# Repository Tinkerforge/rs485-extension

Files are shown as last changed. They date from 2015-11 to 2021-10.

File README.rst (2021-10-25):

RS485 Extension
===============

This repository contains the hardware design files.
The software is included in the Master Brick software
and can be found at https://github.com/Tinkerforge/master-brick

Repository Content
------------------

hardware/:
 * Contains KiCad project files and additionally schematics as PDF

datasheets/:
 * Contains datasheets for sensors and complex ICs that are used

Hardware
--------

The hardware is designed with the open source EDA Suite KiCad
(http://www.kicad.org). Before you are able to open the files,
you have to install the Tinkerforge kicad-libraries
(https://github.com/Tinkerforge/kicad-libraries). You can either clone
them directly in hardware/ or clone them in a separate folder and
symlink them into hardware/
(ln -s kicad_path/kicad-libraries project_path/hardware). After that you
can open the .pro file in hardware/ with KiCad and from there view and
modify the schematics and the PCB layout.

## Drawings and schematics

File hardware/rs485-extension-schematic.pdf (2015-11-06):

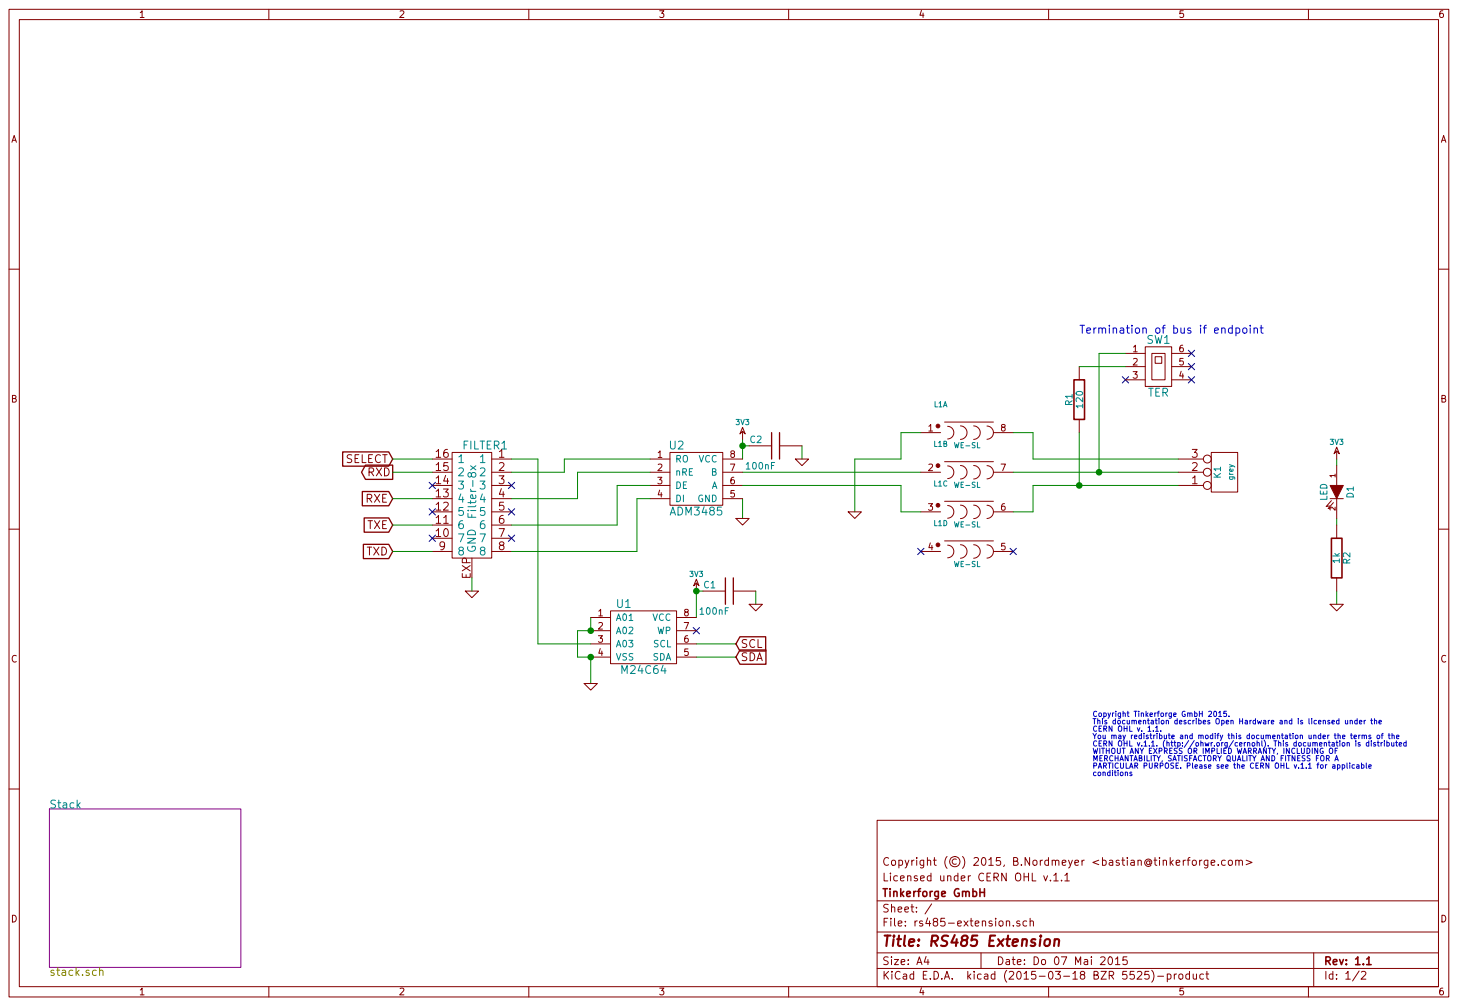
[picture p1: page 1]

Termination of bus if endpoint 1
6 SW1 TER R1 120

Copyright Tinkerforge GmbH 2015. This documentation describes Open Hardware and is licensed under the CERN OHL v. 1.1. You may redistribute and modify this documentation under the terms of the CERN OHL v.1.1. (http://ohwr.org/cernohl). This documentation is distributed WITHOUT ANY EXPRESS OR IMPLIED WARRANTY, INCLUDING OF MERCHANTABILITY, SATISFACTORY QUALITY AND FITNESS FOR A

PARTICULAR PURPOSE. Please see the CERN OHL v.1.1 for applicable
conditions

Licensed under CERN OHL v.1.1 Copyright (©) 2015, B.Nordmeyer <bastian@tinkerforge.com>

File: rs485-extension.sch Sheet: / Tinkerforge GmbH

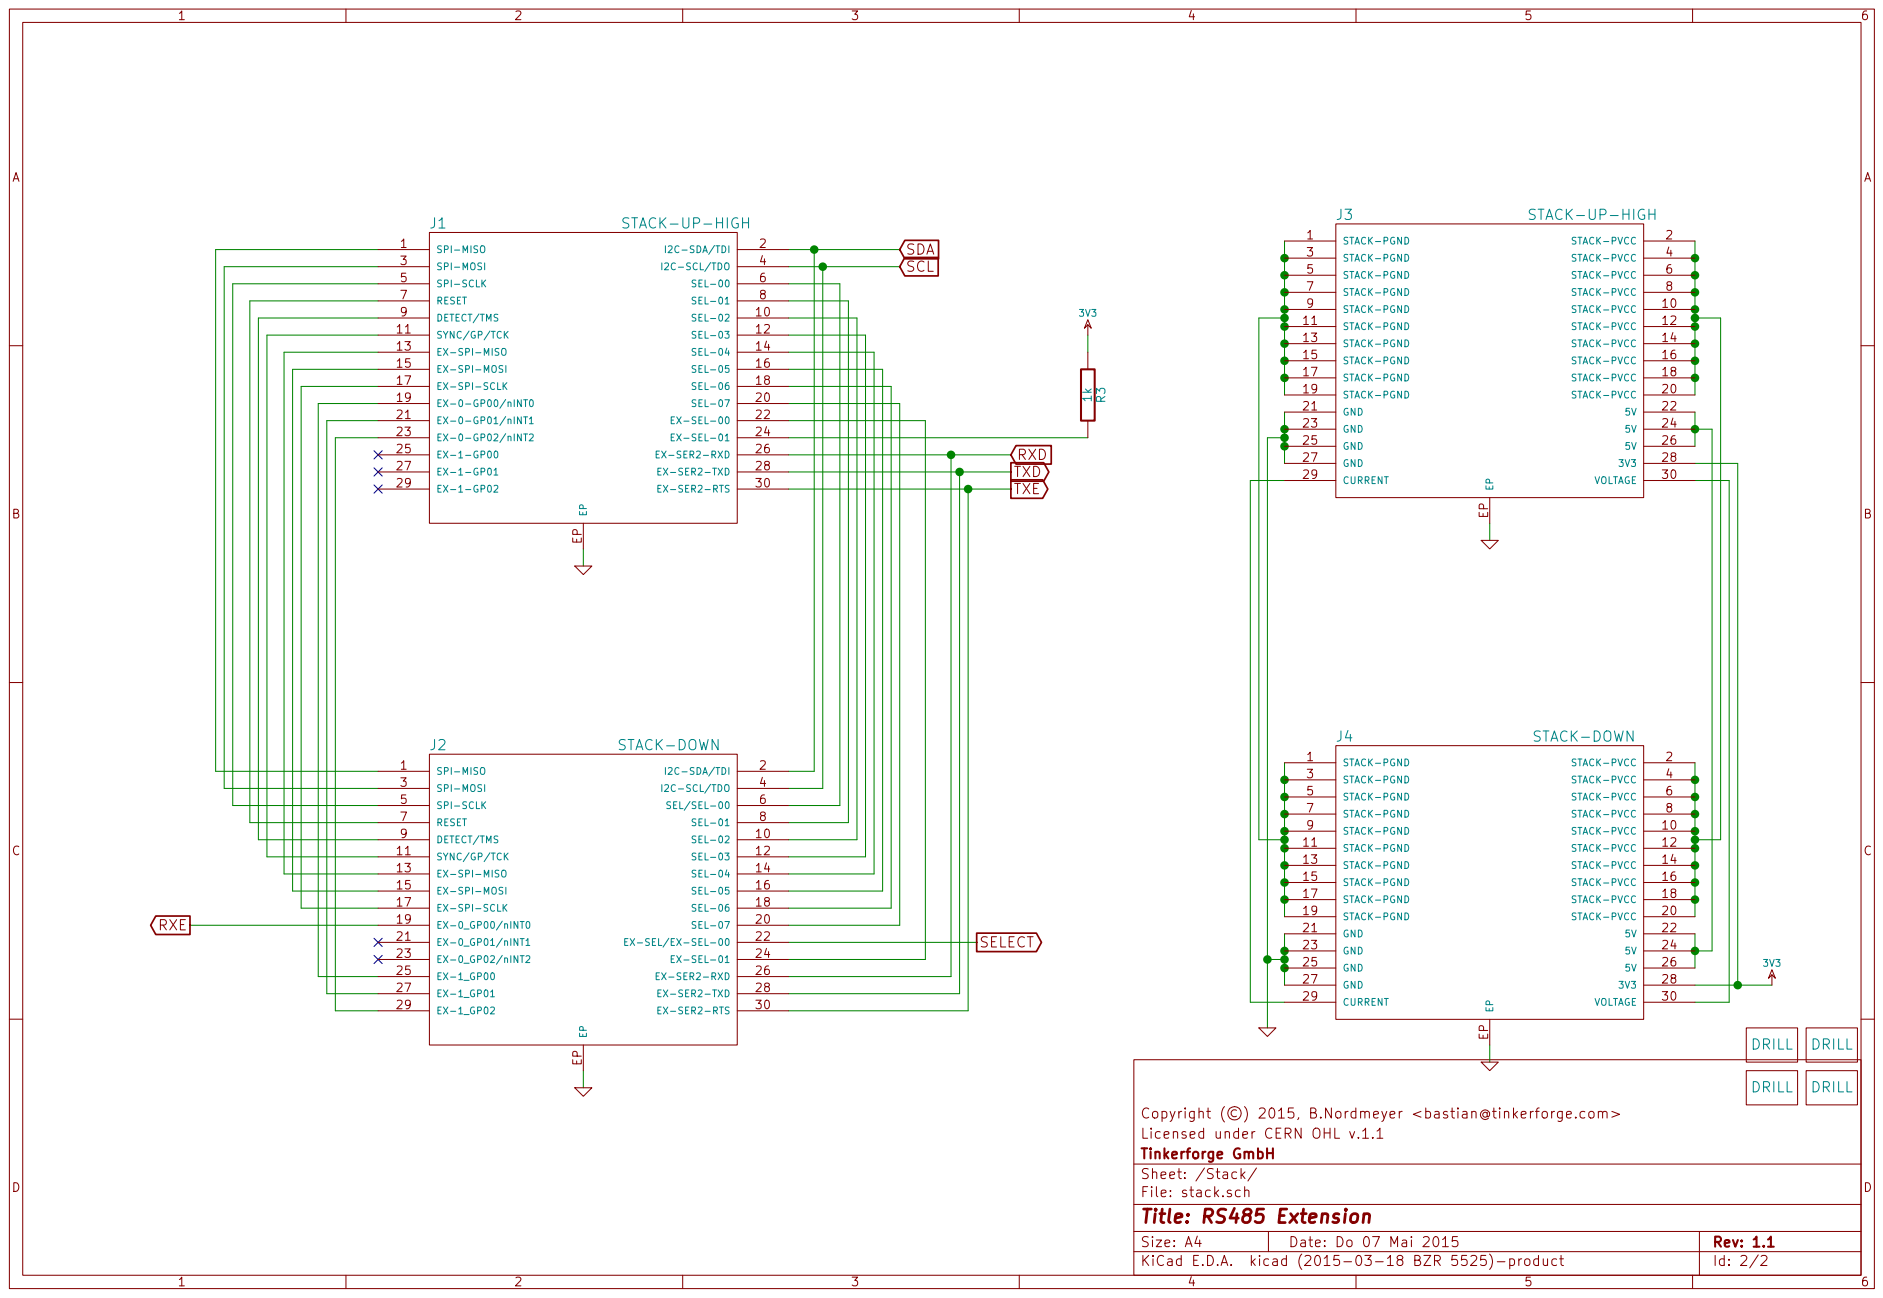
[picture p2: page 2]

Licensed under CERN OHL v.1.1 Copyright (©) 2015, B.Nordmeyer <bastian@tinkerforge.com> RXE

File: stack.sch Sheet: /Stack/ Tinkerforge GmbH

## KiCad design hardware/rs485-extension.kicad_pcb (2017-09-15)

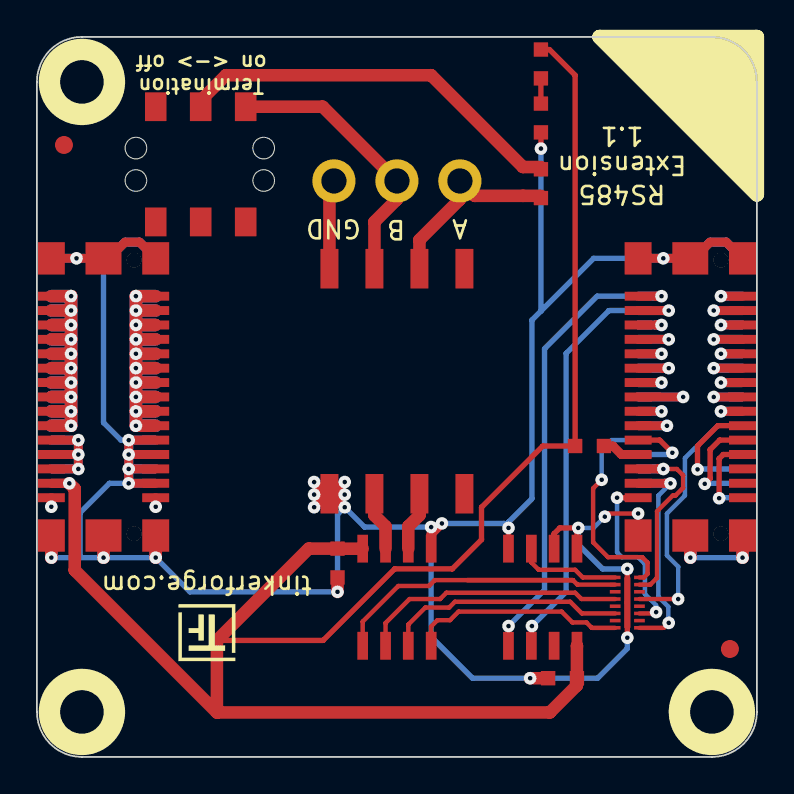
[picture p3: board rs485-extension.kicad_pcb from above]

Board: 2 copper layers, 40.0 x 40.0 mm, 27 parts (0 on the bottom side), 48 nets.

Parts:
C1, C2: 100nF; C0603
D1: LED; D0603
FILTER1: Filter-8x; DFN16-33x135
Fiducial_Mark: VAL**; Fiducial_Mark
Fiducial_Mark#2, Fiducial_Mark#3, Fiducial_Mark#4: VAL**; Fiducial_Mark
J1, J3: STACK-UP-HIGH; BTB08-ACS-TOP
J2, J4: STACK-DOWN; BTB08-ACS-BTM
K1: grey; OQ_3P
L1: WE-SL
R1: 120; R0603
R2, R3: 1k; R0603
Ref**: Val**; Logo_31x31
SW1: TER; SLIDE_SWITCH
U1: M24C64; SOIC8
U2: ADM3485; SOIC8
U3, U4, U5, U6: DRILL; DRILL_NP
VAL: WEEE_7mm
VAL#2: CE_5mm

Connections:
3V3: C1.1, C2.1, D1.1, J3.28, J4.28, R3.1, U1.8, U2.8
GND: C1.2, C2.2, FILTER1.EXP, J1.EP, J2.EP, J3.21, J3.23, J3.25, J3.27, J3.EP, J4.21, J4.23, J4.25, J4.27, J4.EP, L1.1, R2.2, U1.1, U1.2, U1.4, U2.5
unnamed: D1.2, R2.1
unnamed: FILTER1.1, U1.3
unnamed: FILTER1.2, U2.1
unnamed: FILTER1.4, U2.2
unnamed: FILTER1.6, U2.3
unnamed: FILTER1.8, U2.4
unnamed: J1.1, J2.1
unnamed: J1.3, J2.3
unnamed: J1.5, J2.5
unnamed: J1.6, J2.6
unnamed: J1.7, J2.7
unnamed: J1.8, J2.8
unnamed: J1.9, J2.9
unnamed: J1.10, J2.10
unnamed: J1.11, J2.11
unnamed: J1.12, J2.12
unnamed: J1.13, J2.13
unnamed: J1.14, J2.14
unnamed: J1.15, J2.15
unnamed: J1.16, J2.16
unnamed: J1.17, J2.17
unnamed: J1.18, J2.18
unnamed: J1.19, J2.25
unnamed: J1.20, J2.20
unnamed: J1.21, J2.27
unnamed: J1.22, J2.24
unnamed: J1.23, J2.29
unnamed: J1.24, R3.2
unnamed: J3.1, J3.3, J3.5, J3.7, J3.9, J3.11, J3.13, J3.15, J3.17, J3.19, J4.1, J4.3, J4.5, J4.7, J4.9, J4.11, J4.13, J4.15, J4.17, J4.19
unnamed: J3.2, J3.4, J3.6, J3.8, J3.10, J3.12, J3.14, J3.16, J3.18, J3.20, J4.2, J4.4, J4.6, J4.8, J4.10, J4.12, J4.14, J4.16, J4.18, J4.20
unnamed: J3.22, J3.24, J3.26, J4.22, J4.24, J4.26
unnamed: J3.29, J4.29
unnamed: J3.30, J4.30
unnamed: K1.1, L1.6, R1.1
unnamed: K1.2, L1.7, SW1.1
unnamed: K1.3, L1.8
unnamed: L1.2, U2.7
unnamed: L1.3, U2.6
unnamed: R1.2, SW1.2
RXD: FILTER1.15, J1.26, J2.26
RXE: FILTER1.13, J2.19
SCL: J1.4, J2.4, U1.6
SDA: J1.2, J2.2, U1.5
SELECT: FILTER1.16, J2.22
TXD: FILTER1.9, J1.28, J2.28
TXE: FILTER1.11, J1.30, J2.30

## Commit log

2015-11-06 update to new hardware version 1.1
    [rs485-extension.brd, rs485-extension.kicad_pcb, rs485-extension.sch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]
2016-09-29 drc check executed
    [rs485-extension.kicad_pcb]
2017-08-03 Add 3d information (tbc)
    [rs485-extension.kicad_pcb, rs485-extension.sch, stack.sch]
2017-09-15 Add 3d information (final)
    [rs485-extension.kicad_pcb]
2018-02-20 Cleanup KiCad libraries config
    Ensure LibDir=kicad-libraries and LibName1=tinkerforge.
    Remove special library.
2021-10-25 Update KiCad link
    https://www.kicad.org/blog/2021/10/Avoid-links-to-former-kicad-domain/
